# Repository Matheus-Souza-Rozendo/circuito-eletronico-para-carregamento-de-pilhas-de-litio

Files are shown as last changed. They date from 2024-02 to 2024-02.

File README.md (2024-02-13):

# Circuito eletrônico para carregamento de pilhas de lítio

## Problema Inicial
Este projeto deriva de uma solução que foi criada para o cliente Dirceu B. Estes dados estão sendo mostrados com a autorização do mesmo

## Descrição do Projeto
Este projeto busca otimizar a eficiência e reduzir custos ao substituir o uso do Arduino Pro Mini por um circuito dedicado para controlar duas pilhas 18650/3,7V, um voltímetro 2S, um sensor óptico de linha e um micro servo 9g. A proposta inclui a criação de um circuito com saídas específicas para o voltímetro e o servo, além de uma entrada para o sensor, visando simplificação e economia. 

A integração de um BMS para proteção e carregamento das pilhas, juntamente com uma fonte CFTV 9V/2A, será consolidada em um único PCB bivolt, eliminando a necessidade de fontes externas. Em resumo, o projeto visa promover eficiência energética e redução de custos, destacando-se pela integração de componentes em uma solução coesa e adaptável no cenário de desenvolvimento tecnológico.

# Solução Apresentada
## ESTADOS DO SISTEMA
O sistema consiste de um servo motor (micro servo 9g) acionado por uma placa eletrônica. A entrada do sistema é um sensor óptico. Os estados do sistemas são os seguintes

**Estado 1:** Aguardando Acionamento do sensor - Acionado em 0°

**Estado 2:** esperando 1s na posição 0° - Acionado em 0°

**Estado 3:** rotacionando para 180° e aguardando 2s - Acionado em 180°

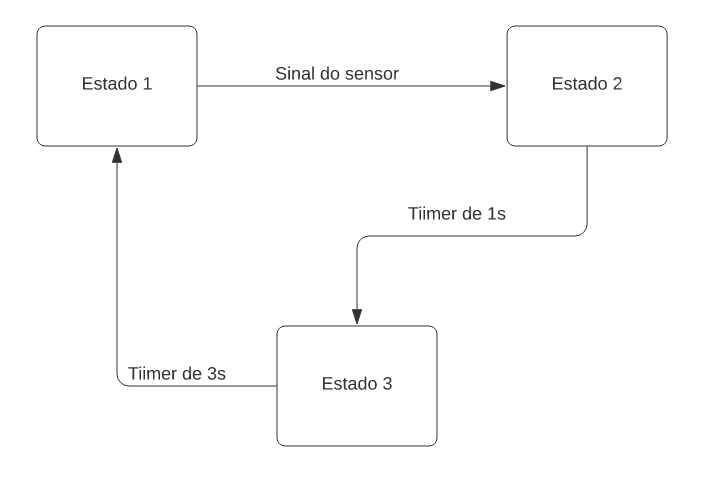
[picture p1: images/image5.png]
Figura 5


É possível notar pela figura 1 que o servo aguarda o sinal do sensor, depois aguarda 1 segundo sendo acionado na posição 0° e depois durante 3s(1s de deslocamento e 2 aguardando) é acionado na posição 180°..
Logo, vale salientar que não é possível realizar a leitura da posição no qual o servo está , usando uma placa sem microprocessador.

## CONTROLE DO SERVO MOTOR
Servomotores tem sua posição controlada variando a largura do pulso PWM, como mostrado na figura

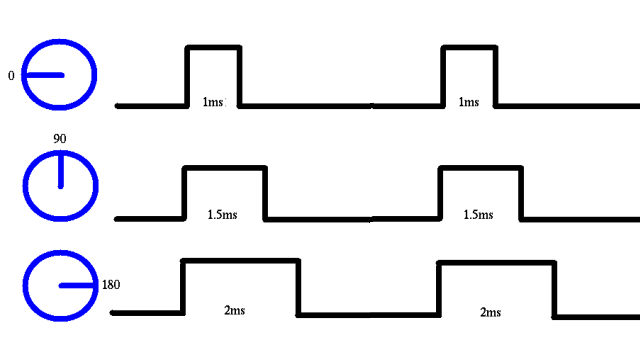
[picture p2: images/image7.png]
Figura 7


Logo, a solução apresentada foi a criação de um circuito que gerasse sinal pwm com largura de 1ms e 2ms.Além disso, esse circuito deveria ser capaz de alterar entre seus dois estados por um controle digital feito por um circuito lógico combinacional.

O circuito resultante é mostrado na figura

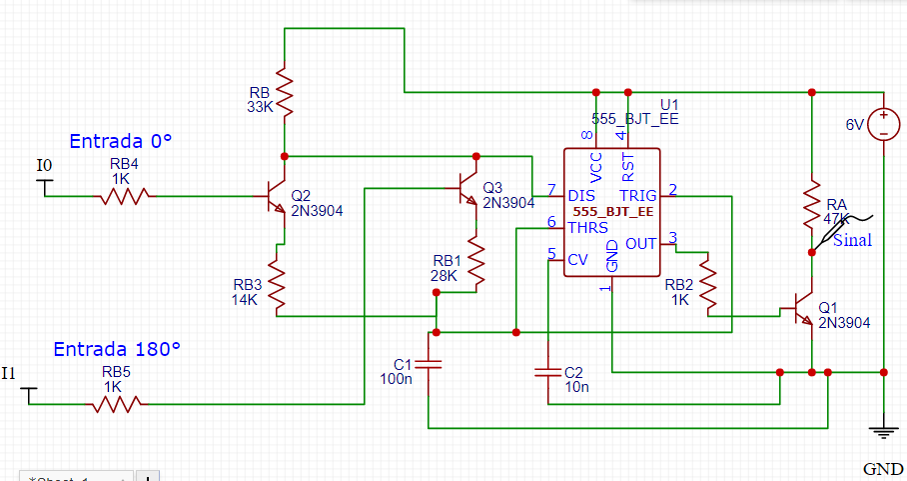
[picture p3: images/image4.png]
Figura 4


Simulações feitas geraram os seguintes resultados

Sinal gerado colocando 6V na entrada 0° 

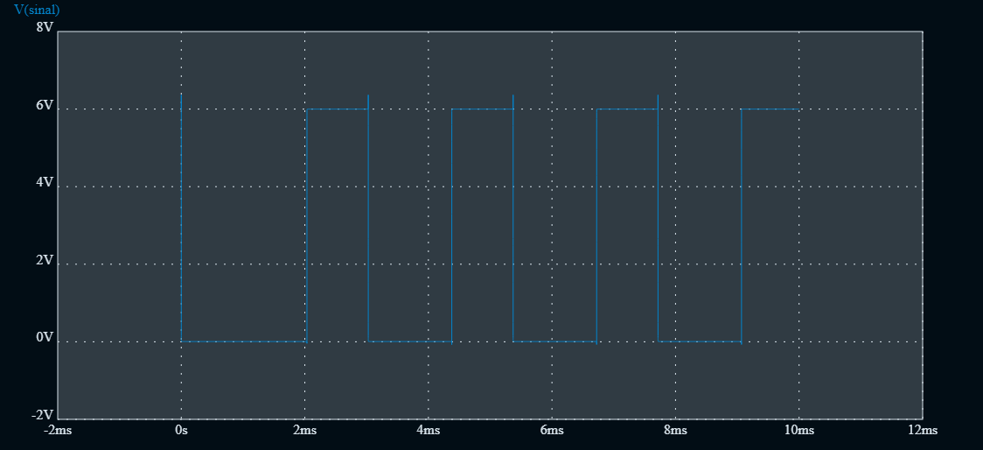
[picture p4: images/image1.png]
Figura 1


Sinal Gerado colocando 6V na entrada 180°

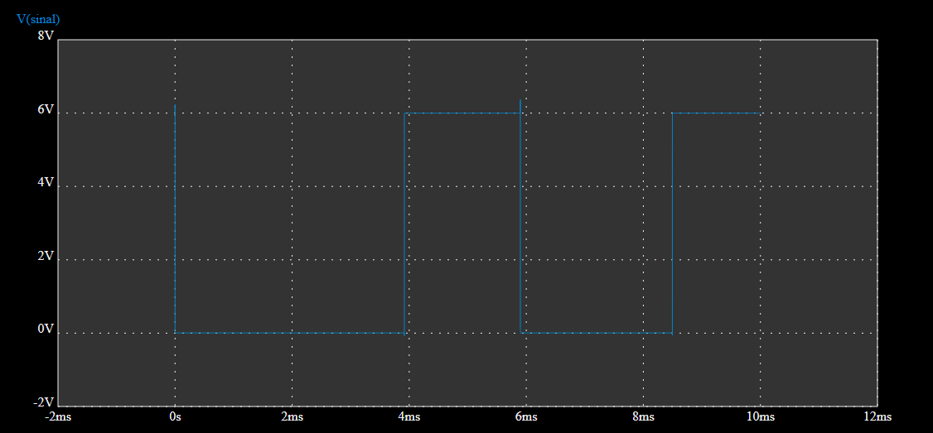
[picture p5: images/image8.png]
Figura 8


## Circuito Timer
Como discutido anteriormente, a transição do estado 1 para o estado 2 e do estado 2 para o estado 3 será feita utilizando-se do sinal proveniente de timers. Por isso, foi construído um circuito no qual um timer 555 no modo monoestável é acionado por um transistor e libera um sinal para a saída de 1 ou 3 segundos a depender da configuração de resistores utilizados.

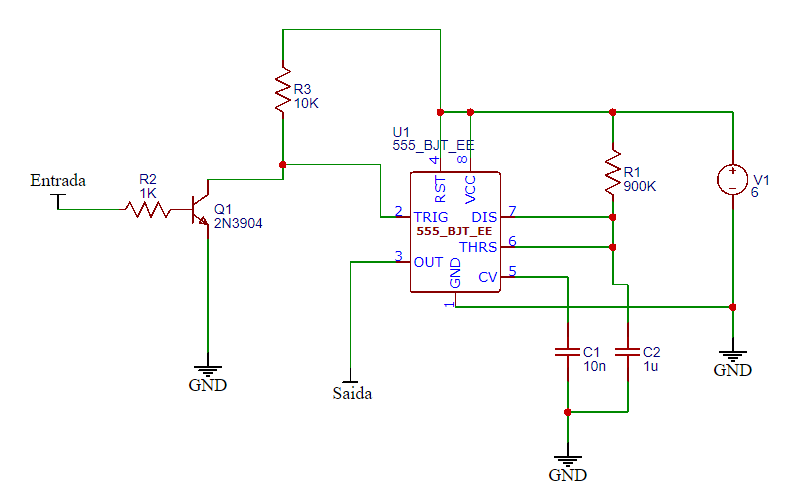
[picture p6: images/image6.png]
Figura 6


Segue os resultados dos testes com esses circuitos

Timer de 1s - R1 de 900 KΩ

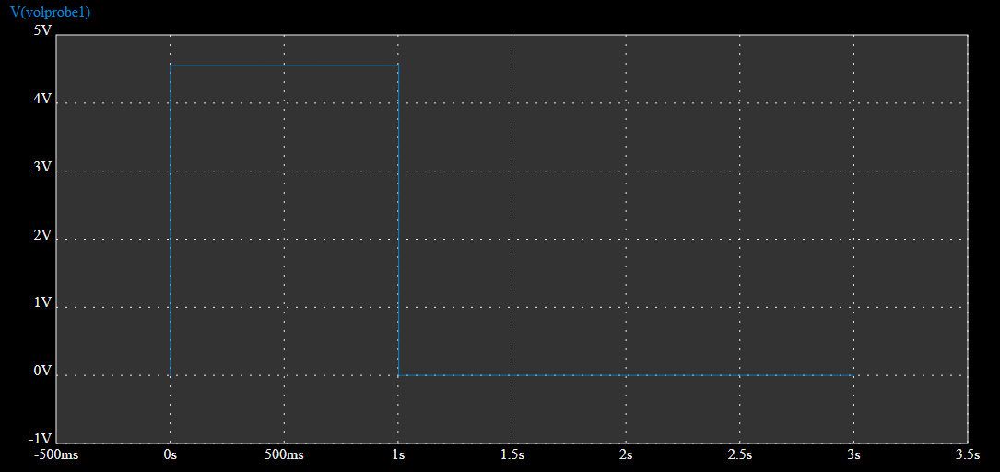
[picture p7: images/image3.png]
Figura 3


Timer de 3s - R1 de 2.7 MΩ

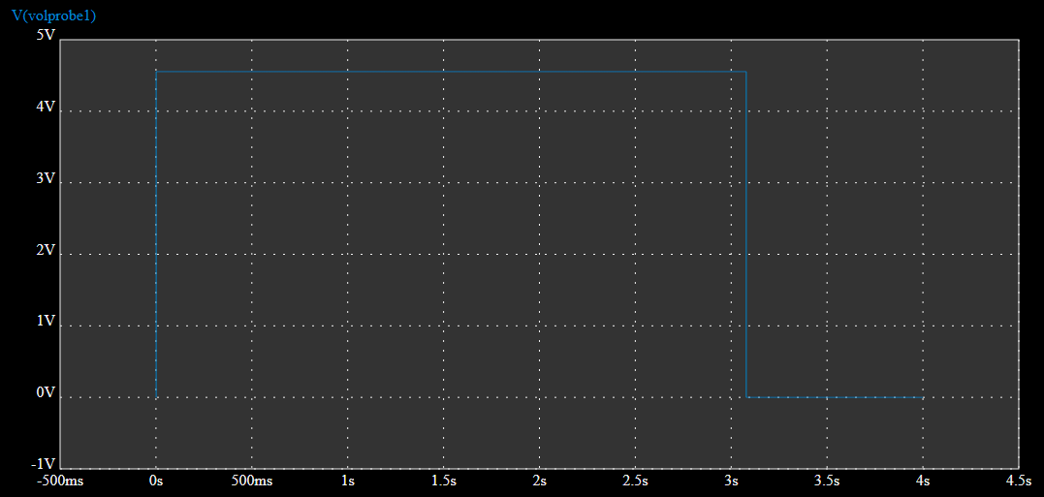
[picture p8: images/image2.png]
Figura 2


## CIRCUITO DIGITAL
Segue o link para baixar a simulação feita no  software circuitMaker

[Circuito Digital](https://github.com/Matheus-Souza-Rozendo/circuito-eletronico-para-carregamento-de-pilhas-de-litio/blob/main/circuito%20logico.CKT)

## FONTE AC/DC PARA CARREGAR PILHAS

O circuito conversor AC/DC segue a linha de uma fonte linear regulada. Sua tensão de entrada é 12V AC. Por isso se faz necessário um transformador 220V para 12V.

A entrada da placa deve ser ligada nos terminais corretos do transformador.

O transformador recomendado é o [Mini Transformador De Energia Ei, Transformador De 220v, 6v, 9v, 12v, 15v, 24v, Entrada Dupla, 12v, 2w, Va - Transformadores - AliExpress.](https://m.pt.aliexpress.com/item/4000042064306.html?gatewayAdapt=Pc2Msite)

Qualquer outro transformador pode ser usado na instalação desde que seja com saída de 12V AC.

É utilizado também um módulo BMS 2S 3A para proteção das baterias de lítio.

Segue o esquema do circuito na figura

[Figura do Circuito](https://raw.githubusercontent.com/Matheus-Souza-Rozendo/circuito-eletronico-para-carregamento-de-pilhas-de-litio/main/images/image9.png)

## Recomendações

Não usar enquanto estiver conectado na tomada para evitar sobrecarga

Utilizar resistores e capacitores com o menor grau de erro possível

Conectar de forma adequada e conforme escrito na placa e no modelo enviado

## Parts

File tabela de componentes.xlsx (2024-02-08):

ID | Name | Designator | Footprint | Quantity | Manufacturer Part | Manufacturer | Price | Pins | Capacitance | Resistance | catid
1 | CD4013B | JK1,JK2 | SOP-14_L8.6-W3.9-P1.27-LS6.0-BL | 2 |  | TEXAS INSTRUMENTS | 1.63 | 14 |  |  | 20
2 | 74HC08 | AND1,AND2 | SOIC-14_L8.7-W3.9-P1.27-LS6.0-BL | 2 |  | TEXAS INSTRUMENTS | 2.78 | 14 |  |  | 20
3 | 74HC04 | NOT | SOIC-14_L8.7-W3.9-P1.27-LS6.0-BL | 1 |  | TEXAS INSTRUMENTS | 2.88 | 14 |  |  | 20
4 | 74HC32 | OR | SOIC-14_L8.7-W3.9-P1.27-LS6.0-BL | 1 |  | TEXAS INSTRUMENTS | 1.48 | 14 |  |  | 20
5 | Capacitor poliester | C1 | RAD-0.1 | 1 |  |  | 0.42 | 2 | 100n
6 | Capacitor poliester | C2,C5,C8 | RAD-0.1 | 3 |  |  | 0.38 | 2 | 10n
7 | Capacitor eletrolitico | C3,C6,C7 | RAD-0.1 | 3 |  |  | 0.23 | 2 | 1u
8 | Capacitor eletrolitico | C4 | RAD-0.1 | 1 |  |  | 0.33 | 2 | 0.1u
9 | GBJ1504 | GBJ11504 | BRIDGE-GBJ | 1 |  |  | 6.96 | 4
10 | LM338 | LM338 | TO220 | 1 |  |  | 6.42 | 3
11 | 2N3904 | 2N3904/1,2N3904/2,2N3904/3,2N3904/5 | TO-92-3_L5.1-W4.1-P1.27-L | 4 | Transistors | ON Semiconductor | 0.25 | 3 |  |  | 20
12 | 2N3904 | 2N3904/6 | TO-92-3_L5.1-W4.1-P1.27-L-1 | 1 | Transistors | ON Semiconductor | 0.25 | 3 |  |  | 20
13 | Resistor | R1 | AXIAL-0.3 | 1 |  |  | 0.05 | 2 |  | 1.6K
14 | Resistor | R2 | AXIAL-0.3 | 1 |  |  | 0.06 | 2 |  | 910K
15 | Resistor | R3,RB2,RB4,RB5 | AXIAL-0.3 | 4 |  |  | 0.05 | 2 |  | 1K
16 | Resistor | R4,R5 | AXIAL-0.3 | 2 |  |  | 0.05 | 2 |  | 10K
17 | Resistor | R6 | AXIAL-0.3 | 1 |  |  | 0.05 | 2 |  | 1800K
18 | Resistor | R7 | AXIAL-0.3 | 1 |  |  | 0.05 | 2 |  | 100
19 | Resistor | R8 | AXIAL-0.3 | 1 |  |  | 0.06 | 2 |  | 270
20 | Resistor | R9 | AXIAL-0.3 | 1 |  |  | 0.05 | 2 |  | 1.5K
21 | Resistor | RA1 | AXIAL-0.3 | 1 |  |  | 0.05 | 2 |  | 47K
22 | Resistor | RB1 | AXIAL-0.3 | 1 |  |  | 0.82 | 2 |  | 27K
23 | Resistor | RB3 | AXIAL-0.3 | 1 |  |  | 0.15 | 2 |  | 14K
24 | Resistor | RB6 | AXIAL-0.3 | 1 |  |  | 0.05 | 2 |  | 33K
25 | Resistor | R10 | R0603 | 1 |  |  | 0.05 | 2 |  | 1k
26 | Resistor | R11 | R0603 | 1 |  |  | 0.05 | 2 |  | 3K
27 | Conector Borne KRE p/ PCI 2 pinos | TRANSFORMADOR,VOLTIMETRO | CONECTOR2WIL2.54ML | 2 |  |  | 1.5 | 2
28 | LM555 | PWM,TIMER1S,TIMER3S | DIP8 | 3 |  | TEXAS INSTRUMENTS | 1.04 | 8
29 | Borne Conector 3 Vias Kre | SERVO,SENSOR,PILHAS | CONECTOR1X3 | 3 |  |  | 1.4 | 3 |  |  | 20
30 | BMS_2S_3A | BM2S3A | BMS_2S_UPDATED | 1 | FDC-2S-2 |  | 11.9 | 5 |  |  | 20
preço em componentes | preço de fabricação da placa | preço total da placa (no varejo)
54.40 | 2.06 | 56.46

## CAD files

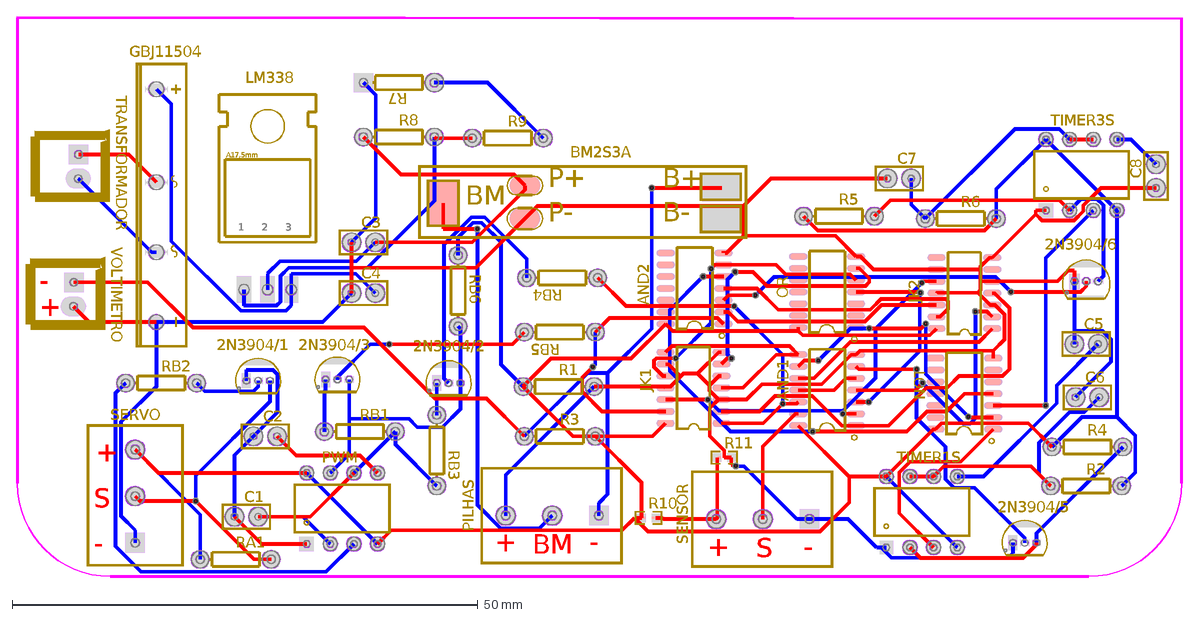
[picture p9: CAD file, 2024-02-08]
PCB_Circuito.dxf
+
-
S
BM
JK1
JK2
AND1
AND2
NOT
OR
C1
C2
C3
C4
C5
C6
C7
C8
GBJ11504
LM338
A17,5mm
1
2
3
2N3904/1
2N3904/2
2N3904/3
2N3904/5
2N3904/6
R1
R2
R3
R4
R5
R6
R7
R8
R9
RA1
RB1
RB2
RB3
RB4
RB5
RB6
R10
R11
TRANSFORMADOR
VOLTIMETRO
PWM
TIMER1S
TIMER3S
SERVO
SENSOR
PILHAS
BM2S3A
B-
P+
P-
B+
